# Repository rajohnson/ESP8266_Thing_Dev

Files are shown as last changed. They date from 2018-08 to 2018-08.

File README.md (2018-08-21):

SparkFun ESP8266 Thing Development Board
========================================

[*SparkFun ESP8266 Thing Development Board  (WRL-13711)*](https://www.sparkfun.com/products/13711)

The project merges the [SparkFun ESP8266 Thing Development Board](https://www.sparkfun.com/products/13711) with 5 level shifters from the [*Logic Level Converter Bi-Directional (BOB-12009)*](https://www.sparkfun.com/products/12009).

Repository Contents
-------------------

* **/Hardware** - Eagle design files (.brd, .sch)

Documentation
--------------

License Information
-------------------

This product is _**open source**_! 

Please review the LICENSE.md file for license information. 

If you have any questions or concerns on licensing, please contact techsupport@sparkfun.com.

Please use, reuse, and modify these files as you see fit. Please maintain attribution to SparkFun Electronics and release anyThing Development Board derivative under the same license.

Distributed as-is; no warranty is given.

- Your friends at SparkFun.

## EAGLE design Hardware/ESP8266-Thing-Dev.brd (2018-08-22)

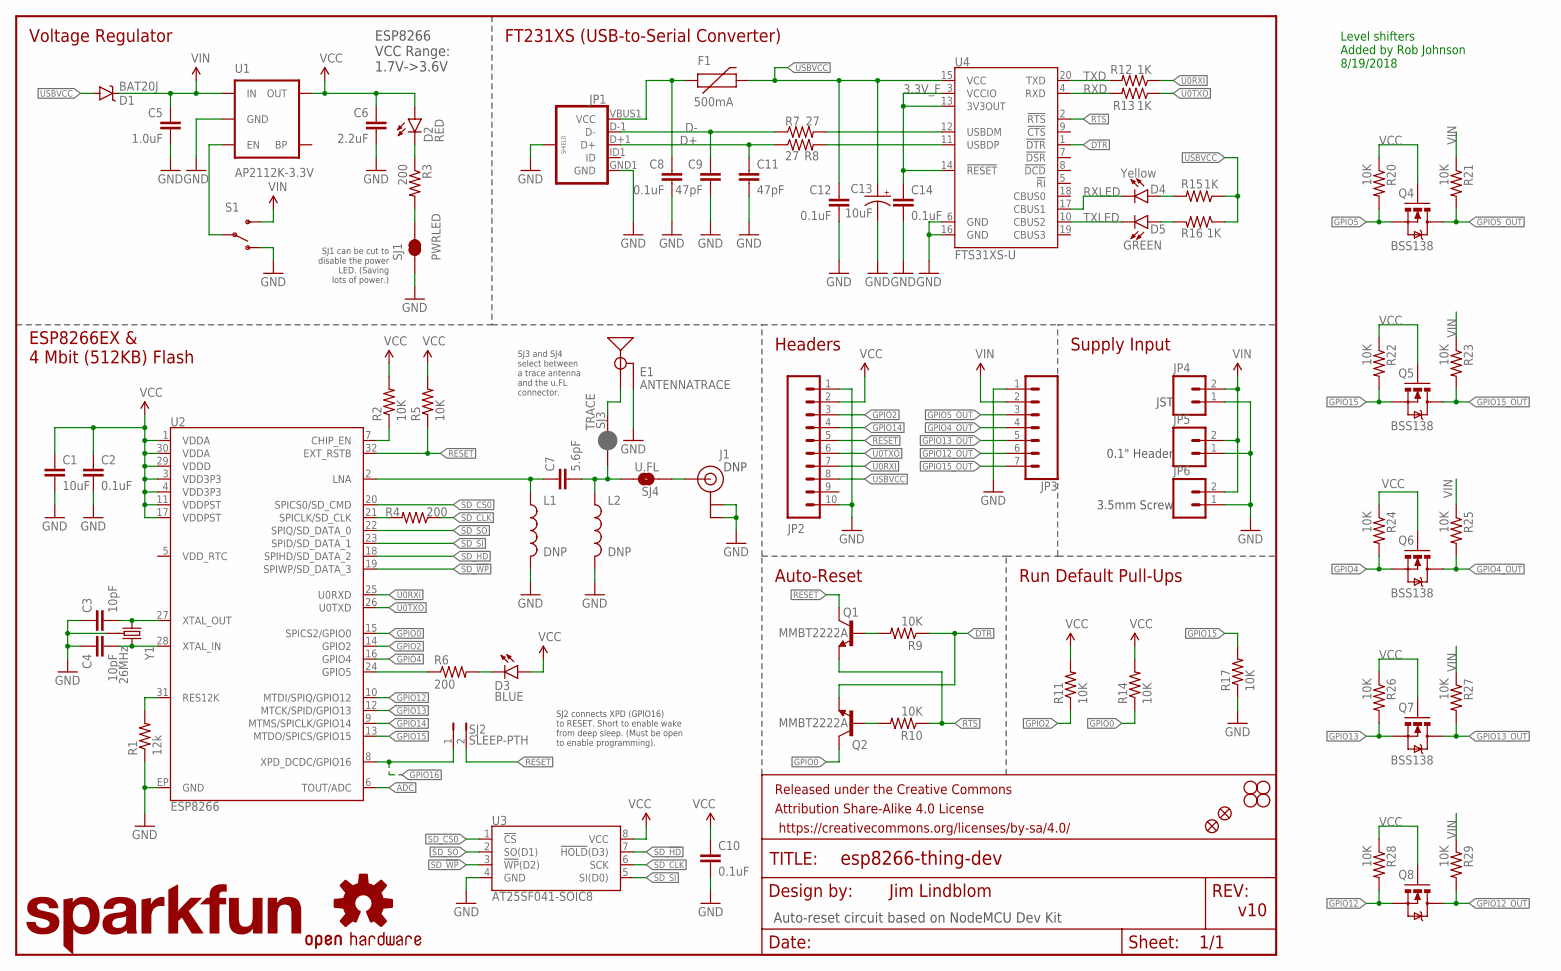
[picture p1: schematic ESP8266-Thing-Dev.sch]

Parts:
C1: 10uF; 0603-CAP
C2, C8, C10, C12, C14: 0.1uF; 0603-CAP
C3, C4: 10pF; 0603-CAP
C5: 1.0uF; 0805
C6: 2.2uF; 0603-CAP
C7: 5.6pF; 0603-CAP
C9, C11: 47pF; 0603-CAP
C13: 10uF; EIA3216
D1: BAT20J; SOD-323
D2: RED; LED-0603
D3: BLUE; LED-0603
D4: Yellow; LED-0603
D5: GREEN; LED-0603
E1: ANTENNATRACE; TRACE_ANTENNA_2.4GHZ_25.7MM
F1: 500mA; PTC-1206
FID1, FID2: FIDUCIAL1X2; FIDUCIAL-1X2
FRAME1: FRAME-LETTER; CREATIVE_COMMONS
J1: DNP; U.FL
JP1: USB_MICROB_PLUGCONN-11752; USB-B-MICRO-SMD_V03
JP2: M10NO_SILK_PTH_FEMALE; 1X10_NO_SILK
JP3: CONN_07NO_SILK; 1X07_NO_SILK
JP4: M02JST-PTH-2; JST-2-PTH
JP5: M021X02_NO_SILK; 1X02_NO_SILK
JP6: M023.5MM-NO_SILK; SCREWTERMINAL-3.5MM-2-NS
L1, L2: DNP; 0603
LOGO1: SFE_LOGO_NAME.2_INCH; SFE_LOGO_NAME_.2
LOGO2: OSHW-LOGOS; OSHW-LOGO-S
Q1, Q2: MMBT2222A; SOT23-3
Q4, Q5, Q6, Q7, Q8: BSS138; SOT23-3
R1: 12k; 0603-RES
R2, R5, R9, R10, R11, R14, R17, R20, R21, R22, R23, R24, R25, R26, R27, R28, R29: 10K; 0603-RES
R3, R4, R6: 200; 0603-RES
R7, R8: 27; 0603-RES
R12, R13, R15, R16: 1K; 0603-RES
S1: SWITCH-SPDT-SMD-A; SWITCH-SPST-SMD-A
SJ1: PWRLED; PAD-JUMPER-2-NC_BY_TRACE_YES_SILK
SJ2: SLEEP-PTH; PTH-JUMPER-2-NO_NO_SILK
SJ3: TRACE; PAD-JUMPER-2-NC_BY_PASTE_NO_SILK
SJ4: U.FL; PAD-JUMPER-2-NO_NO_SILK
STANDOFF1, STANDOFF2, STANDOFF3, STANDOFF4: STAND-OFF
U1: AP2112K-3.3V; SOT23-5
U2: ESP8266; QFN32
U3: AT25SF041-SOIC8; SO08
U4: FTS31XS-U; SSOP20_L
Y1: 26MHz; CRYSTAL-SMD-3.2X2.5

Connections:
3.3V_F: C14.1, U4.3 (VCCIO), U4.13 (3V3OUT), U4.14 (!RESET)
ADC: U2.6 (TOUT/ADC)
ANT: J1.P$3 (SIGNAL), SJ4.1
CHIP_EN: R2.1, U2.7 (CHIP_EN)
D+: C11.1, JP1.D+1 (D+), R8.1
D-: C9.1, JP1.D-1 (D-), R7.1
DTR: Q2.2 (E), R9.1, U4.1 (!DTR)
GND: C1.2, C2.2, C3.1, C4.1, C5.2, C6.2, C8.2, C9.2, C10.2, C11.2, C12.2, C13.C (-), C14.2, E1.GND, E1.GND2 (GND), J1.P$1 (GND), J1.P$2 (GND), JP1.GND1 (GND), JP1.SHIELD1 (SHIELD), JP1.SHIELD2 (SHIELD), JP1.SHIELD3 (SHIELD), JP2.1, JP2.10, JP3.1, JP4.1, JP5.1, JP6.1, L1.2, L2.2, R1.1, R17.1, S1.1 (O), SJ1.1, U1.2 (GND), U2.EP (GND), U3.4 (GND), U4.6 (GND), U4.16 (GND), Y1.2 (GND), Y1.4 (GND)
GPIO0: Q2.3 (C), R14.1, U2.15 (SPICS2/GPIO0)
GPIO2: JP2.3, R11.1, U2.14 (GPIO2)
GPIO4: Q6.2 (S), R24.2, U2.16 (GPIO4)
GPIO4_OUT: JP3.4, Q6.3 (D), R25.2
GPIO5: Q4.2 (S), R6.1, R20.2, U2.24 (GPIO5)
GPIO5_OUT: JP3.3, Q4.3 (D), R21.2
GPIO12: Q8.2 (S), R28.2, U2.10 (MTDI/SPIQ/GPIO12)
GPIO12_OUT: JP3.6, Q8.3 (D), R29.2
GPIO13: Q7.2 (S), R26.2, U2.12 (MTCK/SPID/GPIO13)
GPIO13_OUT: JP3.5, Q7.3 (D), R27.2
GPIO14: JP2.4, U2.9 (MTMS/SPICLK/GPIO14)
GPIO15: Q5.2 (S), R17.2, R22.2, U2.13 (MTDO/SPICS/GPIO15)
GPIO15_OUT: JP3.7, Q5.3 (D), R23.2
GPIO16: SJ2.1, U2.8 (XPD_DCDC/GPIO16)
LNA: C7.1, L1.1, U2.2 (LNA)
LNA2: C7.2, L2.1, SJ3.1, SJ4.2
unnamed: R1.2, U2.31 (RES12K)
unnamed: C4.2, U2.28 (XTAL_IN), Y1.3 (2)
unnamed: C3.2, U2.27 (XTAL_OUT), Y1.1
unnamed: R7.2, U4.12 (USBDM)
unnamed: R3.2, SJ1.2
unnamed: Q1.1 (B), R9.2
unnamed: R8.2, U4.11 (USBDP)
unnamed: D5.A, R16.2
unnamed: D3.C, R6.2
unnamed: D4.A, R15.2
unnamed: D2.C, R3.1
unnamed: Q2.1 (B), R10.2
unnamed: S1.2, U1.3 (EN)
RESET: JP2.5, Q1.3 (C), R5.1, SJ2.2, U2.32 (EXT_RSTB)
RTS: Q1.2 (E), R10.1, U4.2 (!RTS)
RXD: R13.2, U4.4 (RXD)
RXLED: D4.C, U4.17 (CBUS1)
SD_!HD!: U2.18 (SPIHD/SD_DATA_2), U3.7 (!HOLD!(D3))
SD_!WP!: U2.19 (SPIWP/SD_DATA_3), U3.3 (!WP!(D2))
SD_CLK: R4.1, U3.6 (SCK)
SD_CLK0: R4.2, U2.21 (SPICLK/SD_CLK)
SD_CS0: U2.20 (SPICS0/SD_CMD), U3.1 (!CS!)
SD_SI: U2.23 (SPID/SD_DATA_1), U3.5 (SI(D0))
SD_SO: U2.22 (SPIQ/SD_DATA_0), U3.2 (SO(D1))
TRACE_ANT: E1.ANT (SIGNAL), SJ3.2
TXD: R12.2, U4.20 (TXD)
TXLED: D5.C, U4.10 (CBUS2)
U0RXI: JP2.7, R12.1, U2.25 (U0RXD)
U0TXO: JP2.6, R13.1, U2.26 (U0TXD)
USBVCC: C12.1, C13.A (+), D1.A, F1.2, JP2.8, R15.1, R16.1, U4.15 (VCC)
VCC: C1.1, C2.1, C6.1, C10.1, D2.A, D3.A, JP2.2, Q4.1 (G), Q5.1 (G), Q6.1 (G), Q7.1 (G), Q8.1 (G), R2.2, R5.2, R11.2, R14.2, R20.1, R22.1, R24.1, R26.1, R28.1, U1.5 (OUT), U2.1 (VDDA), U2.3 (VDD3P3), U2.4 (VDD3P3), U2.11 (VDDPST), U2.17 (VDDPST), U2.29 (VDDD), U2.30 (VDDA), U3.8 (VCC)
VIN: C5.1, D1.C, JP3.2, JP4.2, JP5.2, JP6.2, R21.1, R23.1, R25.1, R27.1, R29.1, S1.3 (S), U1.1 (IN)
VUSB: C8.1, F1.1, JP1.VBUS1 (VCC)

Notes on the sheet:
ESP8266EX & 4 Mbit (512KB) Flash
ESP8266 VCC Range: 1.7V->3.6V
Voltage Regulator
FT231XS (USB-to-Serial Converter)
Headers
Auto-Reset
Supply Input
JST
0.1" Header
3.5mm Screw
Run Default Pull-Ups
SJ2 connects XPD (GPIO16) to RESET. Short to enable wake from deep sleep. (Must be open to enable programming).
SJ1 can be cut to disable the power LED. (Saving lots of power.)
Jim Lindblom
v10
DNP
Auto-reset circuit based on NodeMCU Dev Kit
SJ3 and SJ4 select between a trace antenna and the u.FL connector.
Level shifters Added by Rob Johnson 8/19/2018

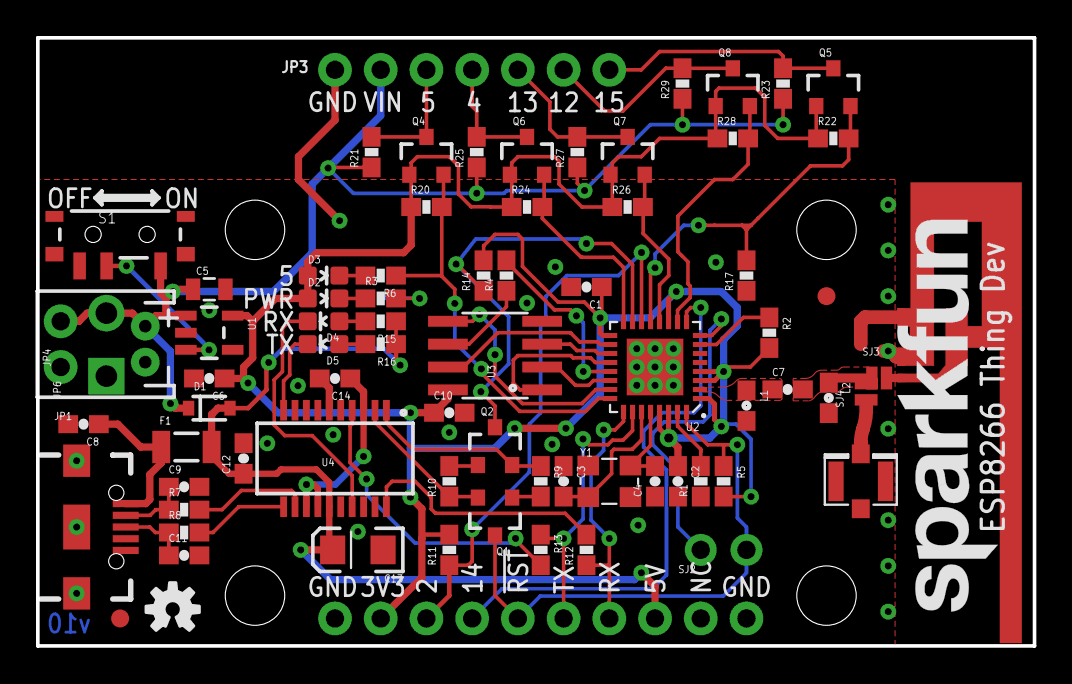
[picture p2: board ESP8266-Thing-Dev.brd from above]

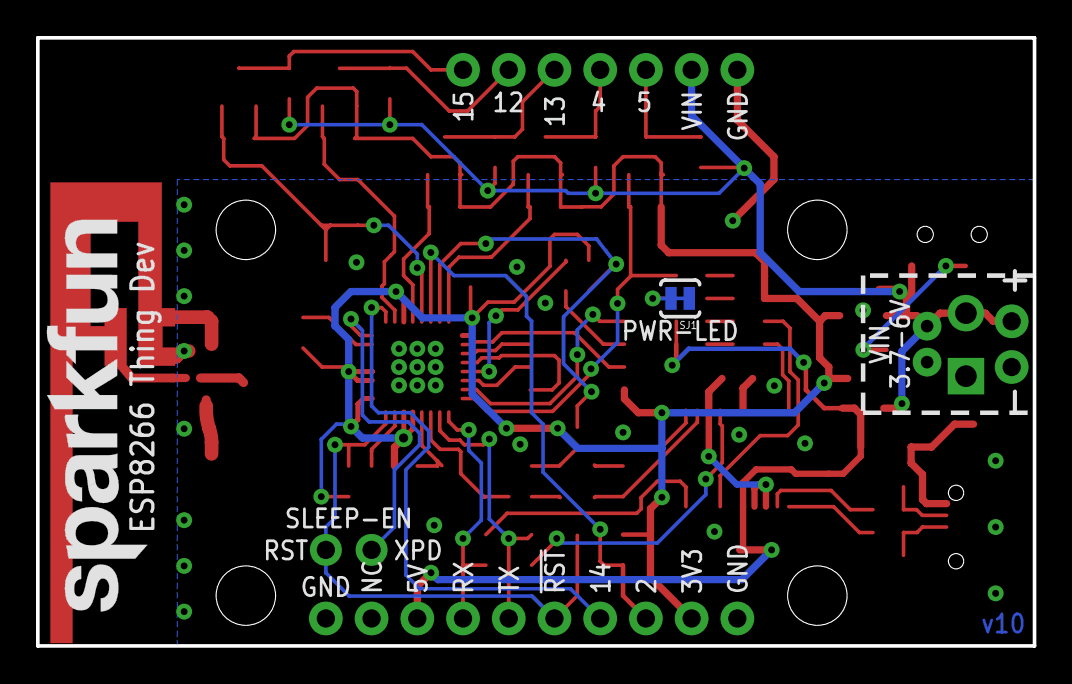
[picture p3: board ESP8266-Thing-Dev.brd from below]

Board: 2 copper layers, 55.4 x 33.8 mm, 84 parts (2 on the bottom side), 56 nets.

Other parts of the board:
LOGO3: SFE_LOGO_NAME.2_INCH; SFE_LOGO_NAME_.2

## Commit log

2018-08-20 Import project and add level shifters in schematic.
    [ESP8266-Thing-Dev.brd, ESP8266-Thing-Dev.sch]
2018-08-20 Fix Net names for level shifter supply voltages
    [ESP8266-Thing-Dev.brd, ESP8266-Thing-Dev.sch]
2018-08-20 Move level shift transistors above appropriate parts. Just a stopping point for the night.
    [ESP8266-Thing-Dev.brd]
2018-08-20 Move level shifter on GPIO 0 to GPIO 15.
    [ESP8266-Thing-Dev.brd, ESP8266-Thing-Dev.sch]
2018-08-20 Switch to 7 pin header. Make board outline larger.
    [ESP8266-Thing-Dev.brd, ESP8266-Thing-Dev.sch]
2018-08-21 Remove panelized PCB.
    [ESP8266-Thing-Dev_Panel_v10.brd]
2018-08-21 Position level shifter components.
    [ESP8266-Thing-Dev.brd]
2018-08-21 Route level shifter nets and start cleaning up DRC warnings.
    [ESP8266-Thing-Dev.brd]
2018-08-22 Route last traces. Add gerbers. Clean DRC.
    [ESP8266-Thing-Dev.brd]
2018-08-22 Update gerbs.
    [ESP8266-Thing-Dev.brd]

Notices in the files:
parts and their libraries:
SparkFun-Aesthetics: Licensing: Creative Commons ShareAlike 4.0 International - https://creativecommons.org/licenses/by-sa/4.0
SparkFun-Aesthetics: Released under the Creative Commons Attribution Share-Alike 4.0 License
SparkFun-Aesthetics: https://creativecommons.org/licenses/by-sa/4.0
